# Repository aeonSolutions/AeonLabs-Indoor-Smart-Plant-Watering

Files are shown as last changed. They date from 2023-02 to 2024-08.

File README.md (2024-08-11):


 
 

<a href="https://trackgit.com">
trackgit-views
</a>




[](https://www.buymeacoffee.com/migueltomas)

<p align="center">
   
</p>

[PCB-Prototyping-Catalogue](https://github.com/aeonSolutions/PCB-Prototyping-Catalogue)  >>   [Home-Automation](https://github.com/aeonSolutions/PCB-Prototyping-Catalogue/tree/main/Home-Automation)  >>  [Safety & Health](https://github.com/aeonSolutions/AeonLabs-Safety-Health)    >>  Indoor Smart Plant Watering

⚠️ **Start by reading the documentation first**. [Click here to open it](https://github.com/aeonSolutions/AeonLabs-Safety-Health/wiki) 

# Indoor Smart Plant Watering

**The Problem**

Anyone loves to have some plants nearby, even when living in an apartment building. However, few know, or have devices to do proper indoor plant care. The main culprit is the absence of water and dry soil.

Furthermore, nowadays is commonly found online, when reading the news, another case and victim of light aggression, in particular, using some kind of diode laser light: red, green, yellow, or blue. And more dangerous, ultraviolet (UV) or infrared (IR) lasers.

**The Idea**

This Smart Indoor plant monitoring and watering is designed to be inserted into any indoor plant vase. Is able to measure and calculate the moisture content in the vase, and when detects low water contents, activates the water pump. Is able to connect to a local home server to upload indoor temperature, humidity, and air quality measurement data. This way, the owner, can have a history record database, without the need for expensive cloud subscriptions.  Additionally, it features a 6 LED system composed of an ultraviolet LED, an Infrared LED and an RGB LED, when combined with multiple devices like this one in the same room is able to perform some basic light aggression protection from an unknown light source outside during the night & day. 

If you prefer can read this project on Autodesk's Instructables.com website, [here](https://www.instructables.com/Indoor-Smart-Plant-Watering/).

<br>

### Status

 Fully tested and working

<br>

### Known PCB bugs
This public revision of the PCB electronics has a few known small errors. 

<br>

<p align="center">
<a href="https://twitter.com/AeonlabsS/status/1621057949425889280?ref_src=twsrc%5Etfw">
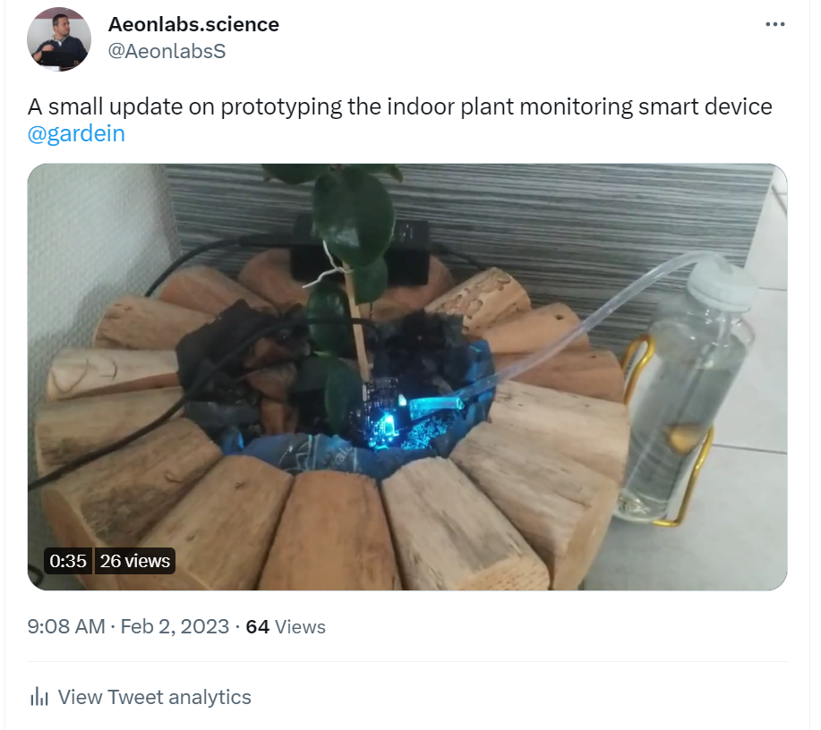
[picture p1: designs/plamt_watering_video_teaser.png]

</a>

<blockquote class="twitter-tweet"><p lang="en" dir="ltr">A small update on prototyping the indoor plant monitoring smart device <a href="https://twitter.com/gardein?ref_src=twsrc%5Etfw">@gardein</a> <a href="https://t.co/ORobUAjV0F">pic.twitter.com/ORobUAjV0F</a></p>&mdash; Aeonlabs.science (@AeonlabsS) </blockquote>
</p>

<br>

<p align="center">
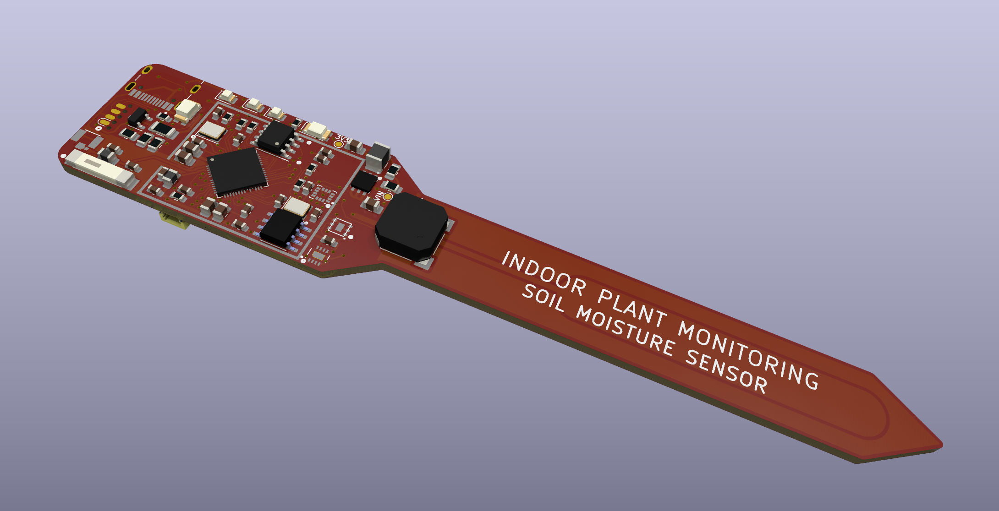
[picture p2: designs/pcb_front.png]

</p>

<br>

## Compatibility

<p align="center">
 <a href"https://www.apple.com/shop/accessories/all/homekit">

 </a>
<a href="https://home.google.com"> 
 
 </a>
<a href="https://www.home-assistant.io">  
 
 </a>
<a href="https://csa-iot.org/all-solutions/matter/">  
 
 </a>
<a href="https://csa-iot.org/all-solutions/matter/">  
 
 </a>
</p>

<br>

### Made by other Makers
 - [Soil Sensor](https://github.com/GewoonMaarten/soil-sensor) by [Maarten](https://github.com/GewoonMaarten)

<br>

## What one additionally needs
- [USB to UART/USB TTL firmware burner for 5V and 3.3V MCUs ](https://github.com/aeonSolutions/PCB-Prototyping-Catalogue/blob/main/DIY-Maker/README.md) 
<br />
<br />

**Get a Notification on every PCB update**

| [](https://www.tindie.com/stores/aeonlabs/) | You can fill in your [email here (Google form)](https://docs.google.com/forms/d/e/1FAIpQLScErMgQYRdA-umvCjvTPPrCO7Lg1QYowTxb7vfa8cTfrcPEAA/viewform?usp=pp_url) and I'll send a reminder when a new PCB prototype is made available here or a new revision for an existing PCB. Stay tuned! |
|---|---|

<br />

## Buy the PRO version on Tindie

| [](https://www.tindie.com/stores/aeonlabs/) | To all those not into electronics and still liked and want to own any of the listed PCB for smart devices can buy the PRO version on Tindie ready to install and use. |
|---|---|

### Useful links 
Below is a list of links with useful information about these kinds of abusive and many times criminal and terrorist usages.
[continue reading ...](https://github.com/aeonSolutions/AeonLabs-Safety-Health/wiki/Useful-Links)

<br />
<br />

**Get a Notification on every PCB update**

| [](https://www.tindie.com/stores/aeonlabs/) | You can fill in your [email here (Google form)](https://docs.google.com/forms/d/e/1FAIpQLScErMgQYRdA-umvCjvTPPrCO7Lg1QYowTxb7vfa8cTfrcPEAA/viewform?usp=pp_url) and I'll send a reminder when a new PCB prototype is made available here or a new revision for an existing PCB. Stay tuned! |
|---|---|

<br>

**Hire AeonLabs** <br>
If you like my work here and are looking to design and deploy your own smart device find [here](https://github.com/aeonSolutions/PCB-Prototyping-Catalogue/wiki/How-to-Hire-AeonLabs) how to hire me. 

<br>

## Author

You can get in touch with me on my LinkedIn Profile:

#### Miguel Tomas



You can also follow my GitHub Profile to stay updated about my latest projects: 

<br>

### Be supportive of my dedication and work towards technology education and buy me a cup of coffee
The PCB Design Files I provide here for anyone to use are free. If you like this Smart Device or use it, please consider buying me a cup of coffee, a slice of pizza, or a book to help me study, eat, and think new PCB design files.

[](https://www.buymeacoffee.com/migueltomas)

<br />

### Make a donation on Paypal
Make a donation on PayPal and get a TAX refund*.

(http://paypal.me/mtpsilva)

### License

Before proceeding to download any of AeonLabs open source code for software solutions and/or open hardware electronics for smart devices and data acquisition make sure you are choosing the right license for your project. See [AeonLabs Solutions for Open Hardware & Open Source Code](https://github.com/aeonSolutions/PCB-Prototyping-Catalogue/wiki/AeonLabs-Solutions-for-Open-Hardware-&-Source-Development) for more information. For commercial business solutions contact AeonLabs for more information ℹ️ using the contacts above. Thank you 🙏.

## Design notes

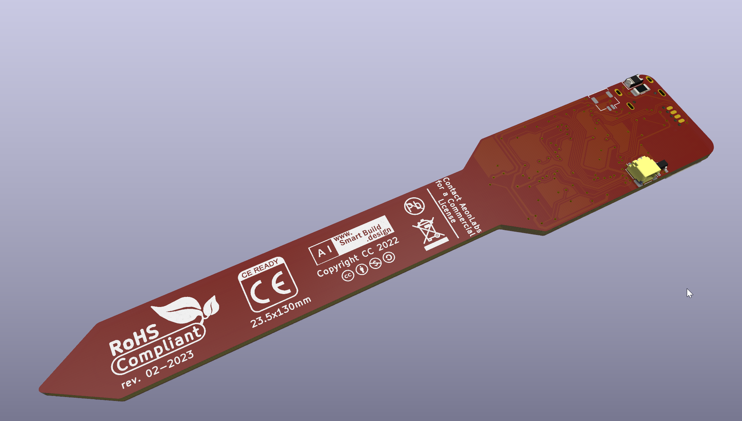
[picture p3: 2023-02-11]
designs/pcb_back.png

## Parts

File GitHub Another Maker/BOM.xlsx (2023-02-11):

Id | Designator | Package | Quantity | Designation | Supplier and ref | Column1 | _1
2 | U2,U1 | 53 | 2 | Keystone 534-553
4 | SW1 | SW_SPST_PTS810 | 1 | C&K PTS810SJG250SMTRLFS
5 | IC2 | SOP100P600X175-10N | 1 | LB1930MC-AH
6 | IC1 | ESP32WROVERM203QL3264PH3Q0 | 1 | ESP32-WROVER | Must be WROVER module, it is the only module which works down to 1.8v
7 | J1 | PinHeader_1x04_P2.54mm_Vertical | 1 | For ESP32 Flashing
8 | J2 | PinHeader_1x02_P2.54mm_Vertical | 1 | Indicator Alfa Zeta C30NR in red/green
9 | R1 | R_0603_1608Metric | 1 | 10K
10 | C3 | C_0603_1608Metric | 1 | 10uF
11 | C2,C1 | C_0603_1608Metric | 2 | 0.1uF

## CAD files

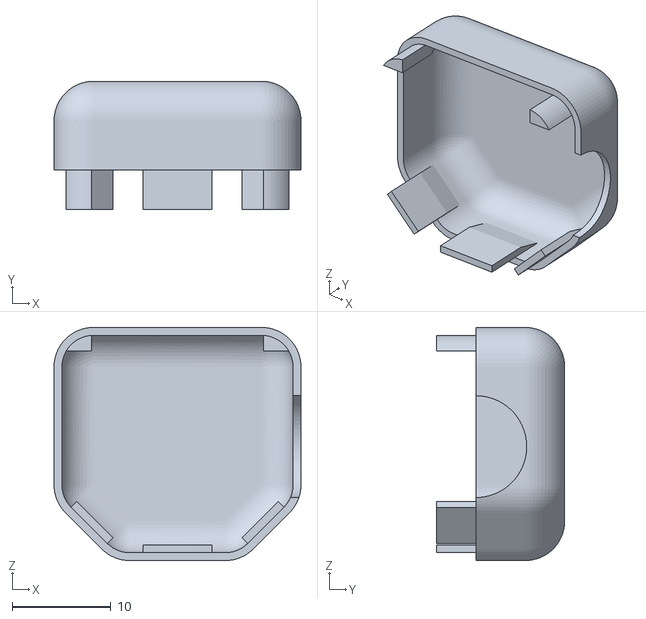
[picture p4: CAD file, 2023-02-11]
GitHub Another Maker/Cap.stl
25.0 x 13.0 x 23.6

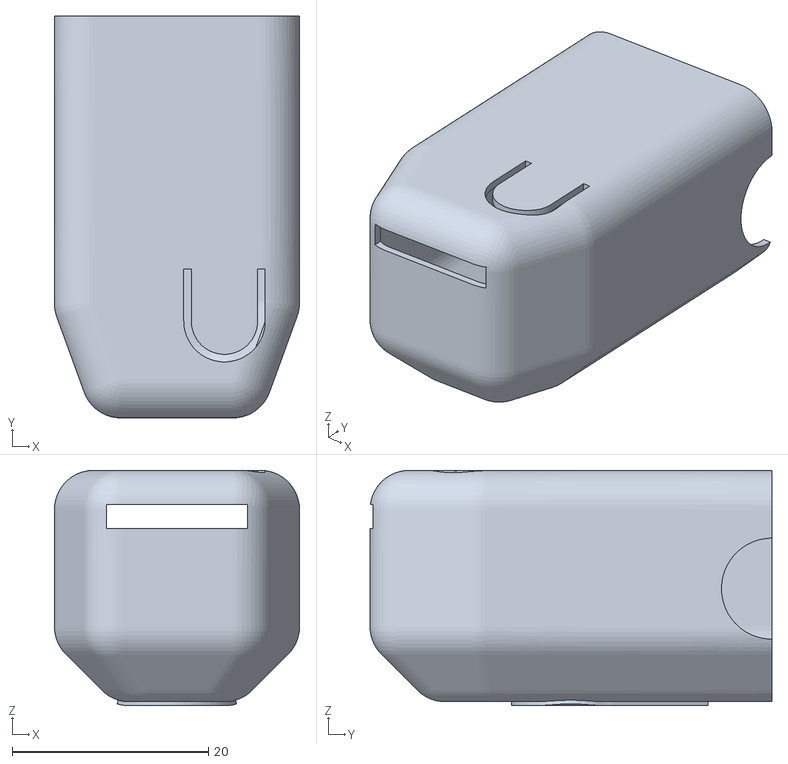
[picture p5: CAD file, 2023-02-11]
GitHub Another Maker/Case.stl
25.0 x 41.0 x 24.0

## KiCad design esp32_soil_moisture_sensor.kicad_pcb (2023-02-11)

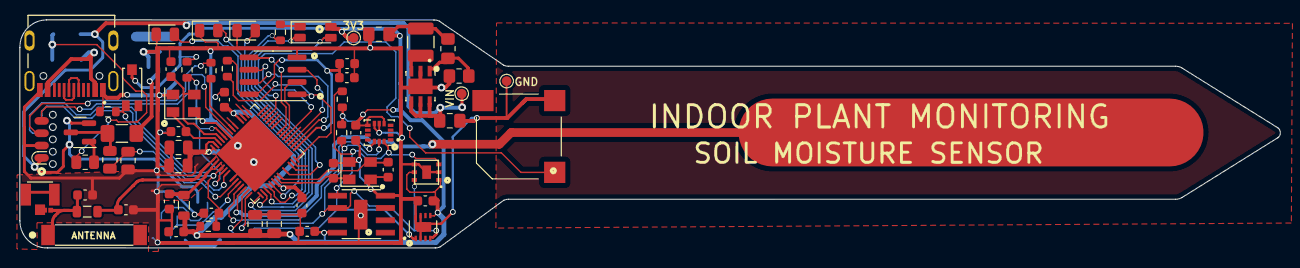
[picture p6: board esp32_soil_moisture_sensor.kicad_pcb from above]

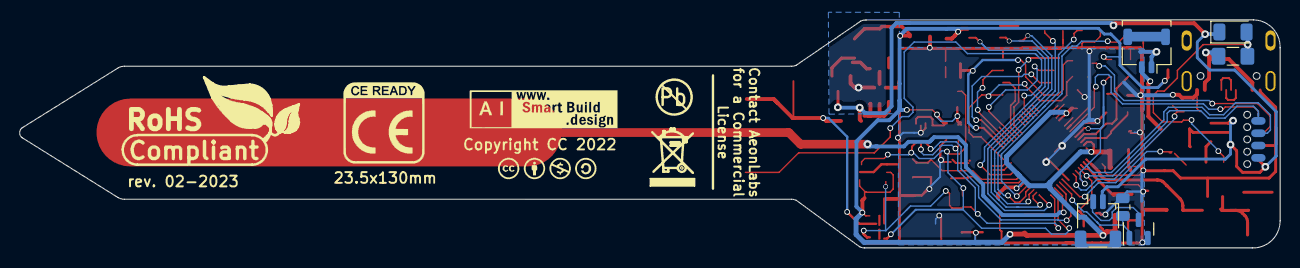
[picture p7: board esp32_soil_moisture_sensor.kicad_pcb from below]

Board: 2 copper layers, 129.9 x 23.5 mm, 71 parts (9 on the bottom side), 46 nets.

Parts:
AC1: 22uF; C_0805_2012Metric_Pad1.18x1.45mm_HandSolder
AC2: 4.7uF; C_0805_2012Metric_Pad1.18x1.45mm_HandSolder
AL1: 3.3uF; L_1210_3225Metric
ANT1: AN9520; AN9520_ANT2-SMD-9.5X2.1X1.0MM
AR1: 24K; R_0805_2012Metric_Pad1.20x1.40mm_HandSolder
AR2: 7k5; R_0805_2012Metric_Pad1.20x1.40mm_HandSolder
AU1: AUR9718x_DFN_3x3mm_6_pin; AUR9718 ST1S09 SON95P300X300X100-7N
AUC1: 100nF; C_0603_1608Metric
BAT2: Screw_Terminal_01x02; JST_SHL_SM02B-SHLS-TF_1x02-1MP_P1.00mm_Horizontal
BZ1: Buzzer; MagneticBuzzer_Kobitone_254-EMB84Q-RO
D12: UV LED; LED_0805_2012Metric
D13: IR LED; LED_0805_2012Metric
D14: WHITE LED; LED_0805_2012Metric
EC12, EC13, EC50, EC51: 22pF 5% 50V; C_0603_1608Metric
EC14: 100pF; C_0805_2012Metric
EC15: 1uF 10% 50V; C_0805_2012Metric
EC16, EC19, EC20, EC24, EC26, EC37, EC38: 100nF 10% 16V; C_0603_1608Metric
EC17, EC18: 10uF 20% 6.3V; C_0805_2012Metric
EC25: 1uF 10% 50V; C_0603_1608Metric
EC40: 100nF; C_0603_1608Metric
ECY1: 40Mhz 22pF+-10PPM; Crystal_SMD_EuroQuartz_MT-4Pin_3.2x2.5mm
ECY2: 32.768Mhz 22pF+-10PPM; Crystal_SMD_EuroQuartz_MT-4Pin_3.2x2.5mm
EL4: 2nH 5%; L_0805_2012Metric
EPS1: ESP32-PSRAM_LY68L6400S; SOIC-8_3.9x4.9mm_P1.27mm
ER1, ER5: 10k; R_0603_1608Metric
ER2: 499R; R_0603_1608Metric
ESP32S3: ESP32-S3; QFN-56-1EP_7x7mm_P0.4mm_EP5.6x5.6mm
F1, F2: Polyfuse; Fuse_1206_3216Metric_Pad1.42x1.75mm_HandSolder
ICR1: 10k; R_0603_1608Metric
ICSP1: Conn_01x08_Male; SOIC_clipProgSmall
IDR1: 10k; R_0603_1608Metric
IMU1: LSM6DS3; LSM6DS3 PQFN50P300X250X86-14N
IMUC1, IMUC2: 100nF; C_0603_1608Metric
J1: U.FL-R-SMT(01); HRS_U.FL-R-SMT(01)
J2: USB_C_TYPE-C-31-M-12; USB C HRO_TYPE-C-31-M-12
L2: 12nH 5%; L_0805_2012Metric
LED1: LED_GBRC; LED_1206_3210_RGB_Metric
LR1: 330R; R_0603_1608Metric
MR3: 390K; R_0805_2012Metric
MR4: 110K; R_0805_2012Metric
MTRR1: 10k; R_0805_2012Metric
MTRT1: NPN; SOT-23
PSR1: 100K; R_0603_1608Metric
PWD1: ss12; D_1206_3216Metric
PWDSWT1: S8050; SOT-23
PWSWR1: 10k; R_0805_2012Metric
SH1: SHT31-DIS; Sensirion_DFN-8-1EP_2.5x2.5mm_P0.5mm_EP1.1x1.7mm
SHJ1: Screw_Terminal_01x02; JST_SH_SM02B-SRSS-TB_1x02-1MP_P1.00mm_Horizontal
Sign-PbFree: LOGO_PBFREE
Sign-RecycleBin: LOGO_RECYCLEBIN_1
Sign-RoHS: LOGO_ROHS_1
TMPR1: 10K; R_0603_1608Metric
TP1: VIN; TestPoint_Pad_D1.0mm
TP2: VOut; TestPoint_Pad_D1.0mm
TP3: GND; TestPoint_Pad_D1.0mm
U1: TEMT6000; TEMT6000-SEN
U2: ATSHA204A-MAHDA-T; ATSHA204A Auth SOIC8
U7: SGP30

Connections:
3V3: AC1.1, AL1.1, AR1.1, AUC1.2, EC14.2, EC15.2, EC16.1, EC17.1, EC18.1, EC19.1, EC26.1, ER1.1, ER5.1, ESP32S3.20 (VDD3P3_RTC), ESP32S3.46 (VDD3P3_CPU), ESP32S3.55 (VDDA), ESP32S3.56 (VDDA), ICR1.1, IDR1.2, IMU1.5 (VDDIO), IMU1.8 (VDD), IMUC1.2, IMUC2.2, L2.1, LED1.4 (K), SH1.5 (VDD), TP2.1, U1.COLLECTOR, U2.8 (VCC), U7.1 (VDD), U7.5 (VDDH)
5V0: F2.1, PWD1.2 (A), PWSWR1.1
BAT_SENSE_IO04: ESP32S3.9 (GPIO4/ADC1_CH3), MR3.2, MR4.1
BUZZER_IO35: BZ1.1 (-), ESP32S3.40 (GPIO35)
CHIP_EN: EC40.2, ER1.2, ESP32S3.4 (CHIP_PU/RESET), ICSP1.5
DC_MOTOR_IO05: ESP32S3.10 (GPIO5/ADC1_CH4), MTRR1.2, MTRT1.1
ESP_GPIO0_BOOT-DTR: ER5.2, ESP32S3.5 (GPIO0/BOOT), ESP32S3.52 (GPIO46), ICSP1.6
GND: AC1.2, AC2.2, AR2.2, AU1.2 (GND), AU1.7 (GND), AUC1.1, BAT2.1, BZ1.2 (+), D12.1 (K), D13.1 (K), D14.1 (K), EC12.2, EC13.2, EC14.1, EC15.1, EC16.2, EC17.2, EC18.2, EC19.2, EC20.2, EC24.2, EC25.2, EC26.2, EC37.2, EC38.2, EC40.1, EC50.2, EC51.2, ECY1.2, ECY1.4, ECY2.2, ECY2.4, EPS1.4 (VSS), ESP32S3.8 (GPIO3/ADC1_CH2), ESP32S3.51 (GPIO45), ESP32S3.57 (GND), ICSP1.2, IMU1.6 (GND), IMU1.7 (GND), IMUC1.1, IMUC2.1, J2.A1B12 (GND), J2.B1A12 (GND), MR4.2, MTRR1.1, MTRT1.2, SH1.2 (ADDR), SH1.7 (R), SH1.8 (VSS), SH1.9 (VSS), TMPR1.1, TP3.1, U2.4 (GND), U7.2 (VSS), U7.4 (R)
GPIO8_I2C_SDA: ESP32S3.13 (GPIO8/ADC1_CH7), IDR1.1, IMU1.14 (SDA), SH1.1 (SDA), U2.5 (SDA), U7.3 (SDA)
GPIO9_I2C_SCL: ESP32S3.14 (GPIO9/ADC1_CH8), ICR1.2, IMU1.13 (SCL), SH1.4 (SCL), U2.6 (SCL), U7.6 (SCL)
IMU_CS_IO06: ESP32S3.11 (GPIO6/ADC1_CH5), IMU1.12 (CS)
LED_BLUE_IO18: ESP32S3.24 (GPIO18/ADC2_CH7/DAC_1), LED1.2 (BA)
LED_GREEN_IO10: ESP32S3.15 (GPIO10/ADC1_CH9), LED1.1 (GA)
LED_IR_IO12: D13.2 (A), ESP32S3.17 (GPIO12/ADC2_CH1)
LED_RED_IO11: ESP32S3.16 (GPIO11/ADC2_CH0), LR1.1
LED_UV_IO14: D12.2 (A), ESP32S3.19 (GPIO14/ADC2_CH3)
LED_WHITE_IO13: D14.2 (A), ESP32S3.18 (GPIO13/ADC2_CH2)
unnamed: AL1.2, AU1.3 (SW)
unnamed: ANT1.1, EC37.1, EL4.1
unnamed: AR1.2, AR2.1, AU1.1 (FB)
unnamed: EC12.1, ECY1.1, ESP32S3.54 (XTAL_P)
unnamed: EC13.1, ECY1.3, ESP32S3.53 (XTAL_N)
unnamed: EC20.1, ESP32S3.2 (VDD3P3), ESP32S3.3 (VDD3P3), L2.2
unnamed: EC38.1, EL4.2, ESP32S3.1 (LNA_IN/RF)
unnamed: EC50.1, ECY2.1, ESP32S3.21 (GPIO15/ADC2_CH4/XTAL_32K_P)
unnamed: EC51.1, ECY2.3, ESP32S3.22 (GPIO16/ADC2_CH5/XTAL_32K_N)
unnamed: ER2.2, ESP32S3.49 (U0TXD/PROG/GPIO43)
unnamed: LED1.3 (RA), LR1.2
unnamed: MTRT1.3, SHJ1.1
unnamed: PWDSWT1.1, PWSWR1.2
RXD0: ESP32S3.50 (U0RXD/PROG/GPIO44), ICSP1.4
SPICLK: EPS1.6 (SCLK), ESP32S3.33 (SPICLK/GPIO30)
SPICS1: EPS1.1 (~CE), ESP32S3.28 (SPI_CS1/GPIO26), PSR1.1
SPID: EPS1.5 (SiO0), ESP32S3.35 (SPID/GPIO32)
SPIHD: EPS1.7 (SIO3), ESP32S3.30 (SPIHD/GPIO27)
SPIQ: EPS1.2 (SIO1), ESP32S3.34 (SPIQ/GPIO31)
SPIWP: EPS1.3 (SIO2), ESP32S3.31 (SPIWP/GPIO28)
TEMT6000_IO01: ESP32S3.6 (GPIO1/ADC1_CH0), TMPR1.2, U1.EMITTER
TXD0: ER2.1, ICSP1.3
USB_D+: J2.A6 (DP1), J2.B6 (DP2)
USB_D-: J2.A7 (DN1), J2.B7 (DN2)
VDD_SPI: EC24.1, EC25.1, EPS1.8 (VCC), ESP32S3.29 (VDD_SPI), PSR1.2
VIN_AUR: AC2.1, AU1.4 (VIN_SW), AU1.5 (VIN_A), AU1.6 (EN), ICSP1.1, PWD1.1 (K), PWDSWT1.2, SHJ1.2, TP1.1
VIN_BAT: F1.1, MR3.1, PWDSWT1.3
VIN_BATF: BAT2.2, F1.2
VIN_USBF: F2.2, J2.A4B9 (VBUS), J2.B4A9 (VBUS)

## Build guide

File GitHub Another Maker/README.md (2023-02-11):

# ESP32 Soil Moisture Sensor
Software and Gerber files for a simple soil moisture sensor using the ESP32 and a bistable status indicator.

More information on the project:
* https://maakbaas.com/esp32-soil-moisture-sensor/logs/logging-to-the-cloud/
* https://hackaday.com/2021/10/28/soil-sensor-shows-flip-dots-arent-just-for-signs/

## Known issues:

* The sensor functionality degraded for me after a few months in use. My hypothesis is that this is due to the PCB material soaking up moisture over time. If this hypothesis is correct, one way to prevent it would be to add epoxy around the PCB edges
* By mistake there is a ground plane underneath the ESP32 Antenna, this should be removed for better WiFi performance
* The code does not do well if there are WiFi connectivity issues. It will try to reconnect until the battery is drained
* Maximum real world battery life I have seen is around 4 months, but solving the previous point might lengthen that

## Photo:

PCB

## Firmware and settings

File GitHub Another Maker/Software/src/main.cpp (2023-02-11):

#include <Arduino.h>
#include <Preferences.h>
#include <WiFi.h>
#include "time.h"
#include <HTTPClient.h>

#define DEBUG

Preferences preferences;

enum status_e{UNKNOWN, RED, GREEN}; 

#ifdef DEBUG
    RTC_DATA_ATTR int bootCount = 0;
#endif
RTC_DATA_ATTR uint16_t threshold = 0;
RTC_DATA_ATTR enum status_e status;

RTC_DATA_ATTR uint16_t measBuffer[24];
RTC_DATA_ATTR uint16_t thresholdBuffer[24];
RTC_DATA_ATTR uint32_t timestampBuffer[24];
RTC_DATA_ATTR uint8_t bufferIndex = 0;

void initWiFi() {
  WiFi.mode(WIFI_STA);
  WiFi.begin("WIFI_SSID", "WIFI_PASSWORD");
  #ifdef DEBUG
    Serial.print("Connecting to WiFi ..");
  #endif
  uint8_t timeout = 0;
  while (WiFi.status() != WL_CONNECTED) {
    delay(1000);
    timeout++;
    if (timeout==10)
        ESP.restart();
  }
  #ifdef DEBUG
    Serial.println(WiFi.localIP());
  #endif
}

void setup() {
    
  // put your setup code here, to run once:
  pinMode(GPIO_NUM_13,OUTPUT);
  pinMode(GPIO_NUM_27,OUTPUT);
  pinMode(GPIO_NUM_26,INPUT_PULLUP);
  #ifdef DEBUG
    Serial.begin(115200);
  #endif

  touch_pad_init();
  touch_pad_set_voltage(TOUCH_HVOLT_2V4, TOUCH_LVOLT_0V5, TOUCH_HVOLT_ATTEN_1V);
  touch_pad_config(TOUCH_PAD_NUM2, 0);
  
  //do measurement 
  uint16_t output;
  touch_pad_read(TOUCH_PAD_NUM2,&output);

  esp_sleep_wakeup_cause_t wakeup_reason;
  wakeup_reason = esp_sleep_get_wakeup_cause();

  switch(wakeup_reason)
  {
    case ESP_SLEEP_WAKEUP_EXT0 : 
        #ifdef DEBUG
            Serial.println("Wakeup caused by external signal using RTC_IO"); 
        #endif

        //debounce button press
        delay(1000);

        //set threshold to current value      
        threshold = output - 5;
        preferences.begin("nvm", false); 
        preferences.putUShort("threshold",threshold);
        preferences.end();

        if (status!=RED)
        {
            //set to red
            digitalWrite(GPIO_NUM_13,HIGH);
            delay(500);
            digitalWrite(GPIO_NUM_13,LOW); 
            status = RED;
        }

        break;
    case ESP_SLEEP_WAKEUP_TIMER : 
        #ifdef DEBUG
            Serial.println("Wakeup caused by timer"); 
        #endif

        //write buffers
        time_t now;
        time(&now);
        timestampBuffer[bufferIndex] = now;
        thresholdBuffer[bufferIndex] = threshold;
        measBuffer[bufferIndex] = output;
        bufferIndex++;

        if (bufferIndex == 24 || (output > threshold && status!=RED))
        {
            //write to DB daily or when watering is needed            
            initWiFi();

            HTTPClient http;
            http.begin("http://192.168.1.90:8086/write?db=plant&u=admin&p=admin");
            http.addHeader("Content-Type", "application/binary");

            char payload[2000], *pos = payload;

            for(int i=0; i<bufferIndex; i++)
            {
                pos += sprintf(pos,"moisture2 level=%d,threshold=%d %d000000000\n",measBuffer[i],thresholdBuffer[i],timestampBuffer[i]);
            }    

            http.POST((uint8_t *)payload, strlen(payload));
            http.end();

            bufferIndex=0;     
        }

        //check the sensor
        if (output > threshold && status!=RED)
        {
            //set to red
            digitalWrite(GPIO_NUM_13,HIGH);
            delay(500);
            digitalWrite(GPIO_NUM_13,LOW); 
            status = RED;
        } 
        else if (output <= threshold && status!=GREEN)  
        {
            //set to green
            digitalWrite(GPIO_NUM_27,HIGH);
            delay(500);
            digitalWrite(GPIO_NUM_27,LOW);
            status = GREEN;
        }

        break;
    default : 
        //do not check the sensor, since the battery is just placed, it can be that it is not placed in the soil
        #ifdef DEBUG
            Serial.printf("Wakeup was not caused by deep sleep: %d\n",wakeup_reason); 
        #endif

        //read EEPROM
        preferences.begin("nvm", true); 
        threshold = preferences.getUShort("threshold");
        preferences.end();

        //set real time clock
        initWiFi();
        configTime(0, 0, "pool.ntp.org");   
        struct tm timeinfo;
        getLocalTime(&timeinfo);
        
        break;
  }

  esp_sleep_enable_ext0_wakeup(GPIO_NUM_26, 0);
  #ifdef DEBUG
    // esp_sleep_enable_timer_wakeup(5000000);
    esp_sleep_enable_timer_wakeup(3600000000);
  #else
    esp_sleep_enable_timer_wakeup(3600000000);
  #endif

  #ifdef DEBUG
    Serial.printf("Sensor value: %d\n",output);
    Serial.printf("Threshold value: %d\n",threshold);
    Serial.printf("Cycle count: %d\n",bootCount);  
    bootCount++;
  #endif

  esp_deep_sleep_start();

}

void loop() {

  // no loop

}

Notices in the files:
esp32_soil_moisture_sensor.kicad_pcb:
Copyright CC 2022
